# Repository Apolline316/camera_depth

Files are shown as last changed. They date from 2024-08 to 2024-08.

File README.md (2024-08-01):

# Depth Camera Usage Guide

In this section, you will learn how to create a depth map, including the software and hardware setup, as well as how to build a box to house all the components.

## Prerequisites

To complete this project, you will need the following components: (include links or sources for these)
- Raspberry Pi 5
- Time-of-Flight (ToF) sensor
- Binocular system composed of 2 IMX219 cameras
- Module V2.2 (camera multiplexer)
- 5V, 5A power supply
- Keyboard and mouse
- Screen with microHDMI cable (choose the type of cable based on your screen)

For building the box, you will need a 3D printer and PLA filament for printing.

You will also need a soldering iron, solder, and wires.

## Installation Guide

To set up a depth camera, first ensure you have all the components listed in the previous section.

The configuration for each component is provided in the respective component's folder.

Follow the installation in this order:

1. Setup the Raspberry Pi
2. Setup the ToF
3. Setup the binocular system

Make sure to match the configuration lines with those in the provided example.

Once these steps are completed, you can proceed to assemble the box and install your system.

## Box Assembly Guide

In this section, we will explain how to assemble the box (final image of the box). You will find the different parts to print in the 3D print folder. Note that supports are not included; you will need to add them during printing.

It is recommended to first follow the previous instructions and ensure that all systems are working before assembling the box. A component might be defective.

1. Connect the CSI cables to the Raspberry Pi.
2. Place the Raspberry Pi in its position. To insert it, angle it slightly due to the USB ports. You will need to apply a bit of force. The USB ports should protrude. You can then check the HDMI and USB-C ports.
3. Connect the CSI cables to the V2.2 module.
4. The V2.2 module comes with 2 standoffs. Insert the standoffs into the holes of the Raspberry Pi.
5. Place the module on the Raspberry Pi and secure it with screws onto the standoffs.
6. Insert the cameras into their designated slots and secure them with screws and bolts.
7. On the front panel: secure the ToF with screws and bolts.
8. Connect all cameras and the ToF to the Raspberry Pi.
9. Attach the front panel of the box: first secure the bottom holes, then the top ones.
10. Connect the microHDMI cable and the power supply.
11. Close the cover and connect the keyboard and mouse.
12. Power on the Raspberry Pi and check the camera connections by opening a terminal.

```bash
libcamera-still --list
```
Here is what you should see:
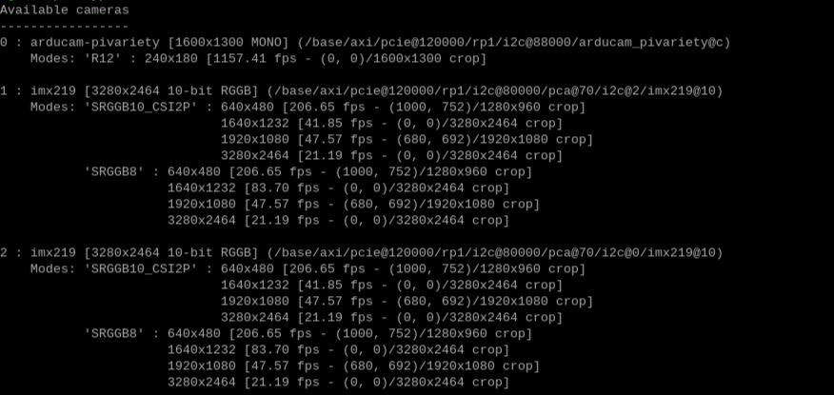
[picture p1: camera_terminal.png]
camera list


If you encounter any issues, repeat the steps. A cable may have become disconnected or may be connected incorrectly.

## Using the Depth Camera
After compiling the code, you can interact with it.

Press the following keyboard keys after clicking on the window you want to interact with:
- `q` to quit
- `s` to save images of the depth map
- `t` to analyze visible objects and determine their distance

To completely stop the code, press `CTRL+C`. However, you will need to restart the Raspberry Pi if you want to run the code again.

## Compilation

To compile the code, use the following line:

```bash
python main.py
```

## Code

### Class `DepthMapProcessor`
This class handles the processing of depth and disparity maps, including segmentation, calculation of average amplitudes, and contour drawing.

#### `__init__`
Initializes the `DepthMapProcessor` class with the provided parameters.

#### `apply_morphological_operations`
Applies morphological operations (dilation and erosion) to the specified image.

#### `calculate_mean_amplitude`
Calculates the mean amplitude for each specified contour.

#### `find_and_draw_contours`
Finds and draws contours in the processed image.

#### `process_contour`
Processes contours by applying morphological operations, finding and drawing contours, and calculating mean amplitudes for the detected contours.

#### `process_disparity_image`
Processes the disparity image by segmenting it according to the defined thresholds, then applying contour processing on each segment.

### Class `DualCameraCapture`
This class manages image capture with two cameras, including validating and displaying captured images.

#### `__init__`
Initializes parameters for image capture with two cameras.

#### `capture_and_save_image`
Captures and saves an image from the specified camera.

#### `display_images`
Displays captured images from specified files.

#### `validate_images`
Validates whether the captured images are acceptable.

#### `capture_images`
Captures a specified number of image pairs and saves them in the specified folder.

### Class `StereoVision`
This class handles stereo vision, including image capture, calculation of disparity and depth maps, and processing of depth maps.

#### `__init__`
Initializes parameters for stereo vision.

#### `stereo_taking`
Captures and rectifies stereo images.

#### `save_images`
Saves the images and the normalized disparity map.

#### `depth_map_calcul`
Calculates the disparity map from the rectified images.

#### `depth_calcul`
Calculates the depth for each pixel from the disparity map.

#### `process_stereo`
Processes the depth map using `DepthMapProcessor`.

#### `capture_and_compute`
Captures images, calculates the disparity and depth maps, and then queues the results.

#### `depth_map_display`
Displays the disparity map and depth from the queued results.

#### `process_and_display`
Creates processes for capturing and computing images, as well as displaying results.

### Functions

#### `folder_create`

Checks if a folder exists, otherwise it creates one.

#### `file_create`

Creates a file of the specified type in a given folder (optional).

#### `show_image`

Displays an image with a specified colormap.

#### `calibrate_cameras`

Calibrates cameras using a calibration process based on photos of a checkerboard.

#### `run_tof_camera`

Runs the ToF camera continuously and updates a queue with depth data.

#### `run_stereo_vision`

Performs stereo vision to obtain disparity and depth results.

#### `terminate_processes`

Terminates the specified processes.

#### `kill_zombie_processes`

Terminates zombie processes detected on the system.

#### `clean_temp_dirs`

Cleans up specified temporary directories.

#### `cleanup`

Performs system cleanup operations and frees up memory.

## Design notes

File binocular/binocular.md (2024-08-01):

# Camera Configuration

In this section, we will see how to configure the 2 IMX219 cameras (or other cameras) on an Arducam camera multiplexer (module V2.2).

<div style="display: flex; justify-content: space-between;">
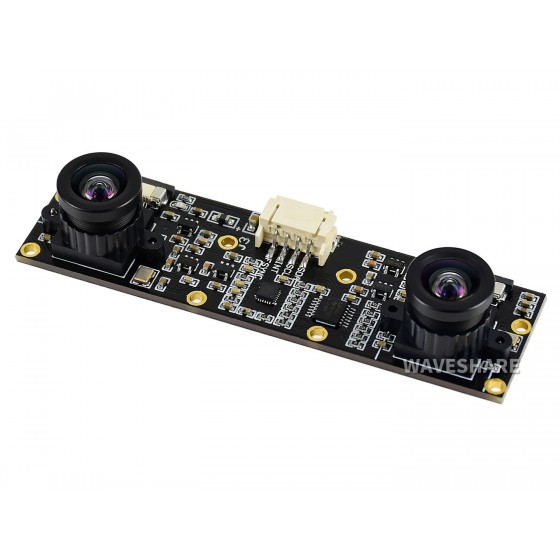
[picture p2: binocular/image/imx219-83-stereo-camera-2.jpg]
Stereo cameras
    
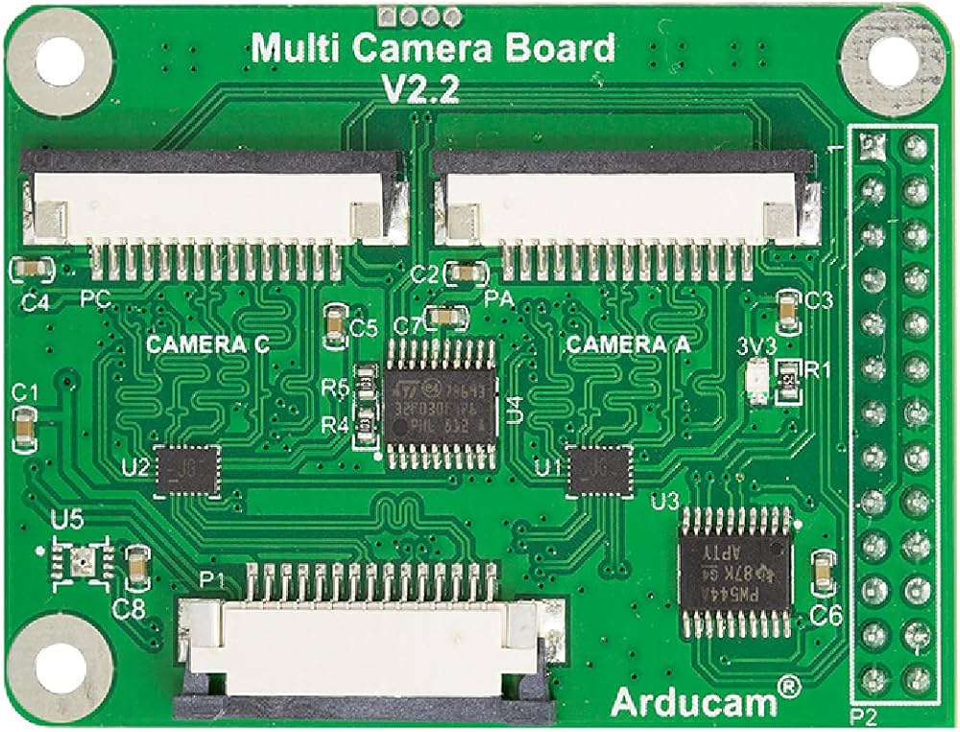
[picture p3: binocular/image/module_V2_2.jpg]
module V2.2
    
</div>

First, make sure you have the appropriate camera cables for use with the V2.2 module.

To get the cameras to work on this module, they must be of the same model.

In a terminal, open the configuration file:
```bash
sudo nano /boot/firmware/config.txt
```

In the configuration file, you will need to add the following lines:
```ini
dtoverlay=arducam-pivariety,cam1
dtoverlay=camera-mux-4port,cam0-imx219,cam2-imx219
```
You will then need to associate each port with its number. Here is the letter-to-number correspondence:
- cam0: A
- cam1: B
- cam2: C
- cam3: D

# Stereo Camera Calibration

In this section, we will see how to calibrate the cameras so they can be used. This calibration will allow us to know the intrinsic and extrinsic parameters of our cameras.

The principle of stereo vision is to have a matrix on the right and left for each camera. Each element of our cameras is stored in dictionaries.

If you want to understand the principle of a binocular system, please refer to the document mathematics_model.pdf. It outlines the mathematical modeling.

To save your calibration, the data is automatically recorded in the 'data' folder. Reuse is also automatic. You will not need to modify the code.

## Calibration Process
To calibrate the cameras, you need a chessboard. You can print the provided file. However, you must ensure it is rigid to prevent calculation errors due to camera distortion.

When you indicate you want to calibrate the cameras by entering 'y', you will have the option to specify the number of rows and columns on the chessboard, as well as the number of images you want to take.

Take different positions with the chessboard. However, make sure it is entirely within the images and close enough to the cameras for the best calibration quality. You can validate or invalidate the taken images if they do not meet your expectations.

## Measurement Process

Images are taken automatically, with delays. However, you can set delays by modifying the class at the time of its declaration in stere_vision.py.

A window will then open to view the map. You can modify the depth camera filter values if necessary, if the result is not satisfactory.

# The Code

## Code Description
In this section, we will see the different classes and functions that allow calculating the depth map, calibrating, and capturing images with the cameras.

## StereoCalibration

### Description
Manages the parameters and processes of stereoscopic calibration for two cameras.

### Methods

#### `__str__(self)`
Returns a string representation of the class attributes.

#### `__init__(self)`
Initializes the calibration parameters for stereo cameras.

#### `save_data(self)`
Saves the calibration parameters in `.npy` and `.csv` files.

#### `rectify(self, frames: list) -> list`
Rectifies the stereoscopic images using the undistortion and rectification maps.

#### `load_data(self, directory: str)`
Loads the calibration parameters from `.npy` files in a specified directory.

## Calibrator

### Description
Manages the calibration process for a pair of stereo cameras.

### Methods

#### `__init__(self, row: int, column: int, square_size: float, image_size: tuple)`
Initializes the parameters for camera calibration.

#### `corner_detect(self, image_pair: tuple)`
Detects the corners of the calibration board in a pair of images.

#### `calibrate_camera(self) -> StereoCalibration`
Calibrates the two cameras and determines their related matrices.

#### `calibration_process(self, nbr_photo: int, image_folder: str) -> StereoCalibration`
Performs the calibration process by reading calibration images and calling the calibration method.

## DualCameraCapture

### Methods

#### `__init__(self)`
Initializes the parameters for capturing images with two cameras.

#### `capture_and_save_image(self)`
Captures and saves an image from the specified camera.

#### `display_images(self)`
Displays the captured images from the specified files.

#### `validate_images(self)`
Validates if the captured images are acceptable.

#### `capture_images(self)`
Captures a specified number of image pairs and saves them in the specified folder.

## StereoVision

### Methods

#### `__init__(self)`
Initializes the parameters for stereo vision.

#### `stereo_taking(self)`
Captures and rectifies stereo images.

#### `save_images(self)`
Saves the images and the normalized disparity map.

#### `depth_map_calcul(self)`
Calculates the disparity map from the rectified images.

#### `depth_calcul(self)`
Calculates the depth for each pixel from the disparity map.

#### `process_stereo(self)`
Processes the depth map using `DepthMapProcessor`.

#### `capture_and_compute(self)`
Captures images, calculates the disparity map and depth, then places the results in a queue.

#### `depth_map_display(self)`
Displays the disparity map and depth from the results in the queue.

#### `process_and_display(self)`
Creates processes for capturing and computing images, as well as for displaying the results.

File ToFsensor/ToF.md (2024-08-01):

# Time-of-Flight (ToF) Sensor Configuration

This document provides instructions for configuring a time-of-flight (ToF) sensor on your Raspberry Pi 5. Initially, we will see how to initialize the sensor on the Raspberry Pi. Once these steps are completed, you will not need to redo them. You can then simply compile the code.

## Required Hardware

Before you start, make sure you have the following items:

- Compatible Raspberry Pi
- Time-of-Flight (ToF) sensor
- GPIO cable (if necessary)
- Male-to-Male Dupont cable

## Configuration Steps

### Connecting to the Raspberry Pi 5

Connect the CSI cable to the cam 0 port (the one closest to the Ethernet connector), and connect the 5V and GND to the pins, as shown in the following schematic:

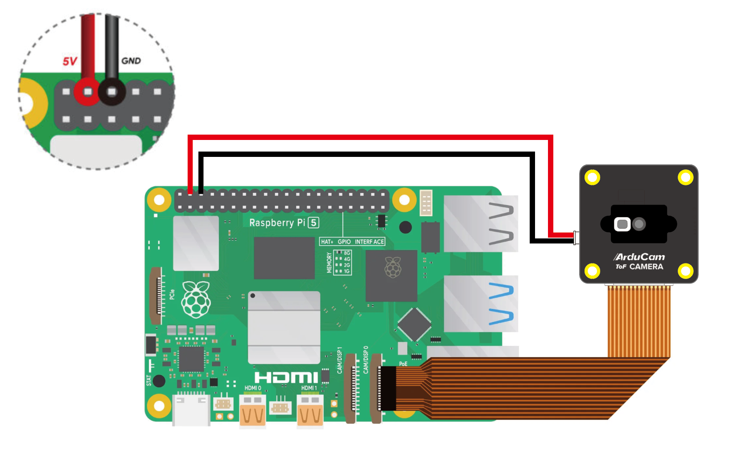
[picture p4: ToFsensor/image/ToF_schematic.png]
Tof sensor connectic


### Step 1. Connect the Arducam ToF Camera to the Raspberry Pi

Note that the Raspberry Pi should remain turned off during the connection, and the power cable should be removed.

### Step 2. Keep Your Raspberry Pi Powered Off

Please keep your Raspberry Pi powered off and activate the recovery on the Arducam ToF camera board using the Dupont line (a male-to-male cable may suffice if you do not have a Dupont line):

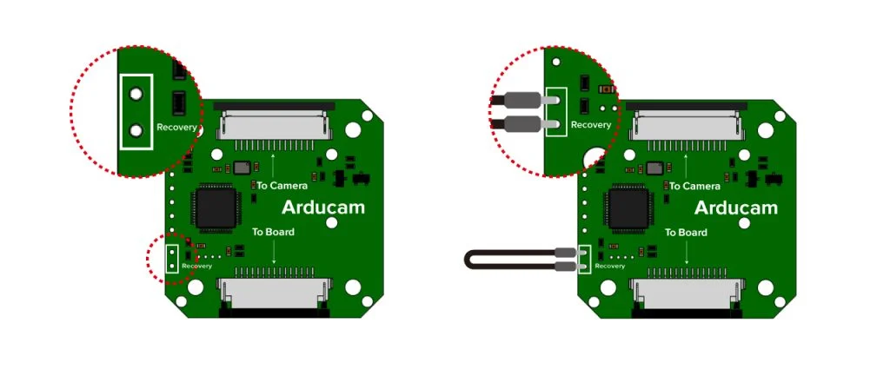
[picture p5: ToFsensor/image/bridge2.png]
Camera Schematic (Step 2)


### Step 3. Turn On Your Raspberry Pi

Please deactivate the recovery after turning on the RPi:

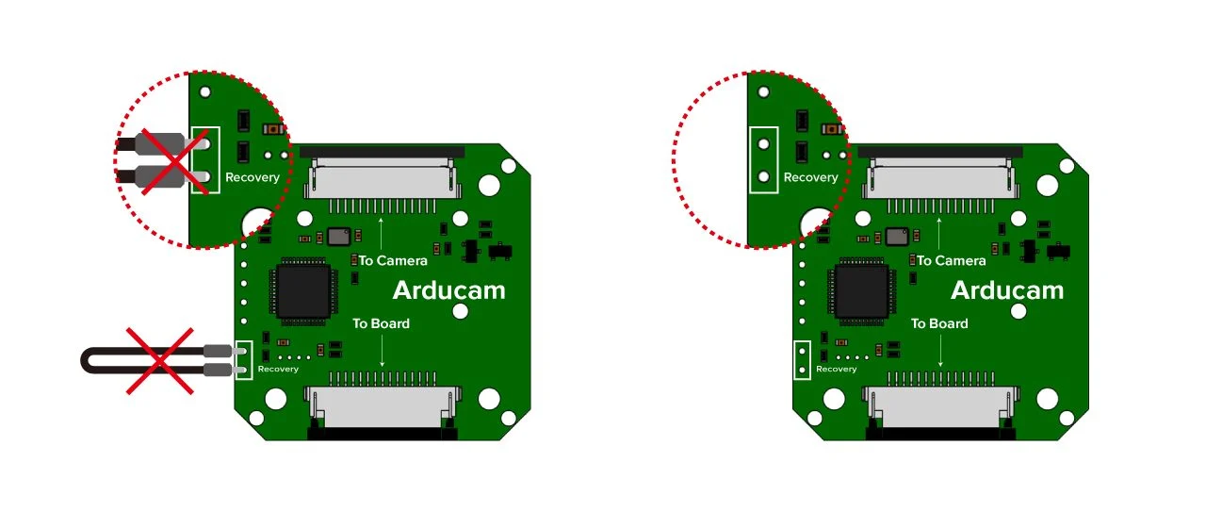
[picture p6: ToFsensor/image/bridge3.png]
Camera Schematic (Step 3)


Simply remove the Dupont line.

## Download the Firmware Update Tool

```bash
B0410_Tof_firmware.tar.gz
```

## Install Dependencies

```bash
sudo apt update -y && sudo apt install -y libtinfo5
```

## Unzip the Update Tool

### Tip

You can check whether your system is 32-bit or 64-bit by using the command `dpkg --print-architecture`. Then, you can execute the following commands based on the version of your operating system:

```bash
tar xzvf B0410_Tof_Firmware.tar.gz
# for a 64 bits system
cd B0410_Tof_Firmware/aarch64/

# for a 32 bits system
cd B0410_Tof_Firmware/armv7l/
```

## Update the Firmware

### Check the I2C Bus

You can then check the I2C connection:

```bash
dmesg | grep arducam
```
You should see the code x-000c.

By default, the code is 4-000c. However, this code may change.

Tof sensor config 1

### Update the I2C Bus

Next, you need to update the firmware. To do this, enter the following line in your terminal:
Make sure to replace `x` with the I2C bus port number.

```bash
sudo ./firmware_update -i x -m b0410_tof_firmware
```

Check that the address is `0xFFFFFFFE` on the first lines.

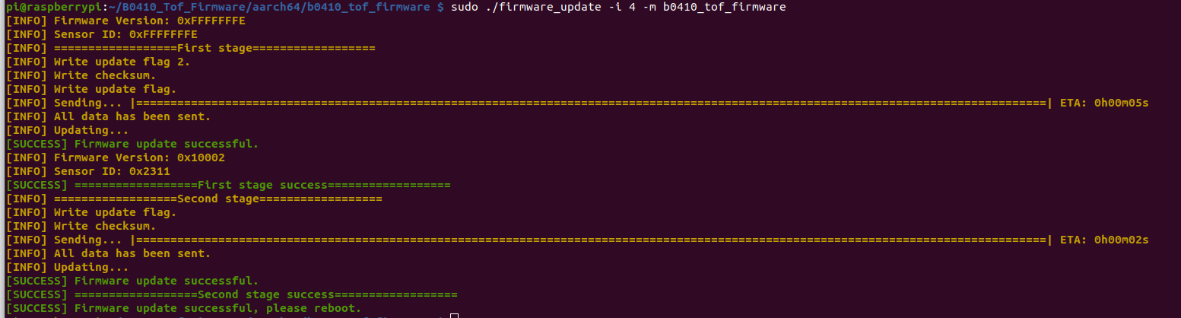
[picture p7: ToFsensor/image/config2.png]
Tof sensor config 2


If not, repeat the steps to connect the sensor. You will need to redo the last 2 steps.

### Reboot

Next, restart your system.

``` bash
sudo reboot
```

## Using the Camera

To use the camera, follow these steps:

### Step 1. Download the Git Repository

``` bash
git clone https://github.com/ArduCAM/Arducam_tof_camera.git
```
### Step 2. Enter in the folder

``` bash
cd Arducam_tof_camera
```
### Step 3. Install the dependencies

``` bash
./Install_dependencies.sh
```
Enter 'y' for reboot the Raspberry Pi.

You can verify thzt the next line is in your config.txt file.

``` bash
dtoverlay = arducam-pivariety,cam0
```

### Step 4. Compile

Compile the code to check its functionality and install any missing components.

``` bash
./compile.sh
```
The live camera feed should then open. Use `Ctrl + C` to stop the code.

### Step 5. Python Configuration

Enter this line in the terminal:
``` bash
./Install_dependencies_python.sh
```

It may be necessary from time to time to redo steps 3 and 4. Indeed, some libraries may need to be updated, or the connection with the ToF sensor might be lost. You do not need to redo step 5.

# The Code

The goal of this code is to operate the ToF sensor through a process. To make it work, please refer to `main.py`.

In the following sections of this guide, we will review the source file `tof_sensor.py`.

## Code Description

### Description

The `TofCamera` class manages image capture from a Time-of-Flight (ToF) camera, processes depth and amplitude data, and displays the results.

### Methods

#### `__init__(self, max_distance: float)`

Initializes the ToF camera with the maximum measurable distance.

#### `process_frame(self) -> np.ndarray`

Processes the captured frame and returns the resulting image.

#### `capture_image(self)`

Saves the resulting image under the name `tof{n}.png`.

#### `process_tof(self)`

Processes the depth map to extract contours.

#### `continuous_display(self)`

Continuously captures and displays images from the ToF camera.

#### `cleanup(self)`

Stops and closes the camera, and destroys all OpenCV windows.

#### `get_depth_buf(self) -> np.ndarray`

Returns the current depth buffer.

#### `get_depth_normalized(self) -> np.ndarray`

Returns the normalized depth map.

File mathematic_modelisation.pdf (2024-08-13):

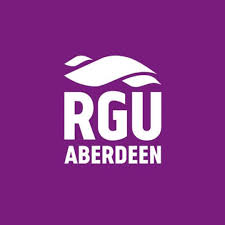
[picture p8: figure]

### MATHEMATIC MODELISATION OF A DEPTH

### CAMERA

### BOYER Apolline

### August 13, 2024

## Contents

2.3.2 Calculating the Transformation Matrix Between the Two

1

Mathematic modelisation of a depth camera

### 1 Introduction

The objective is to do a mathematic modelisation of a depth camera. This depth camera will use a binolucar camera which permits to make a stereo vision of an image. A Time-of-Flight sensor is also used.
First, we will see the modelisation of a binocular system. Then, we will see the modelisation of a Time-of-Flight sensor.

### 2 The Binocular System

Binocular vision, inspired by the human ability to perceive depth and the three-dimensional structure of the world, uses two cameras to capture images of the same scene from slightly different angles. By exploiting disparity, which is the difference in the position of objects in the two images, it is possible to calculate the distance of objects relative to the cameras and thereby reconstruct a three-dimensional scene.

### 2.1 Camera Modeling

A camera is modeled using the pinhole model. It allows the conversion from a 3D image to a 2D image.
This is done through three transformations. The first transformation consists of converting from a 3D reference frame to the camera reference frame. The second transformation allows for a projection onto the image. Finally, the third transformation converts dimensions from mm to pixels.The two last are rerouped in one tranformation.

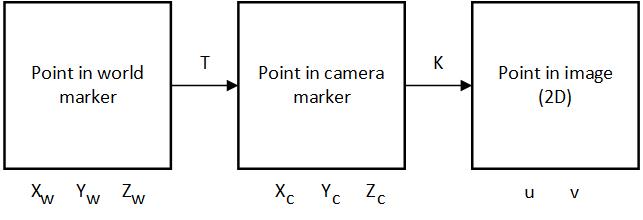
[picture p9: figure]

Figure 1: Schematic of different transformations

First, we take a point M in what is called the world coordinate system. M has coordinates (XW ,YW ,ZW ). The point C is the projection of M (XC ,YC ,ZC ) in the camera reference frame. The point m (u, v) is the projection of C in the image reference frame.

2

Mathematic modelisation of a depth camera

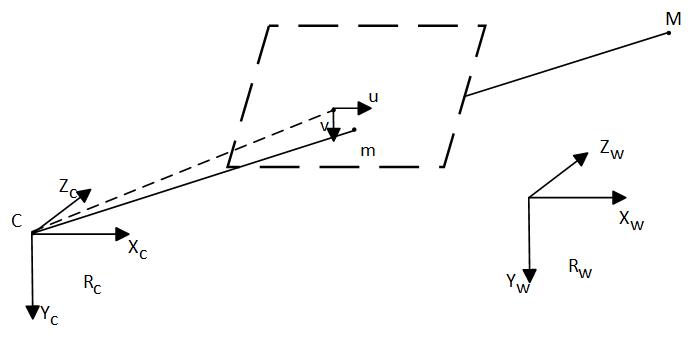
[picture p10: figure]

Figure 2: Schematic for transformation

First of all, we can see the transformation from M to C as a combination of rotations and translations, all in homogeneous coordinates.
The rotation matrices around the three principal axes are defined as follows:

Rotation around the X-axis (angle α) :

Rx (α) =

1 | 0 | 0
0 cosα −sinα
0 | sinα | cosα

Rotation around the Y-axis (angle β) :

Ry (β) =

cosβ | 0 | sinβ
0 | 1 | 0
−sinβ 0 cosβ

Rotation around the Z-axis (angle γ) :

Rz (γ) =

cosγ −sinγ 0
sinγ | cosγ | 0
0 | 0 | 1

The translation vector is:

T (Tx ,Ty ,Tz ) =

| Tx
| Ty
| Tz

In homogeneous coordinates, rotations and translation can be combined into a single transformation matrix T .

3

Mathematic modelisation of a depth camera

The homogeneous transformation matrix T is obtained by combining the rotation matrices and the translation vector:

T =

Ã
R | t
0 | 1!
(1)

Where R is the combined rotation matrix and t is the translation vector.
The combined rotation matrix can be obtained by multiplying the individual rotation matrices (according to the desired order of rotations):

R = Rz (γ)Ry (β)Rx (α)

Thus, the complete homogeneous transformation matrix T is:

T =

cosβcosγ | −cosβsinγ | sinβ | Tx
sinαsinβcosγ+cosαsinγ | −sinαsinβsinγ+cosαcosγ −sinαcosβ Ty
−cosαsinβcosγ+sinαsinγ | cosαsinβsinγ+sinαcosγ | cosαcosβ | Tz
0 | 0 | 0 | 1

(2)

The matrix T corresponds to the extrinsic parameters of the camera.

The intrinsic parameters of a camera are used to transform the 3D coordinates in the camera reference frame into 2D coordinates in the image reference frame. These parameters include the focal lengths fx and f y , as well as the principal point coordinates cx and cy .

The transformation of camera coordinates (XC ,YC ,ZC ) to image coordinates (u, v) is carried out in three steps:
1. Perspective projection: This transformation projects the 3D coordinates onto an image plane.
2. Scaling: This transformation converts the units of the image coordinates from mm to pixels.
3. Translation: This transformation adjusts the image coordinates to account for the principal point of the image.

The intrinsic projection matrix K is defined as follows:

4

Mathematic modelisation of a depth camera

K =

fx | 0 | cx | 0
0 | f y | cy | 0
0 | 0 | 1 | 0

(3)

Thus, for a point C in the camera reference frame with homogeneous coordinates (XC ,YC ,ZC , 1), the homogeneous coordinates of the projected point m in the image reference frame are obtained by:

u
v
1

- = K

XC
YC
ZC
1

=

fx | 0 | cx | 0
0 | f y | cy | 0
0 | 0 | 1 | 0

XC
YC
ZC
1

(4)

By combining the extrinsic and intrinsic transformations, the complete projection matrix M of the camera is:

M = K ·T =

fx | 0 | cx | 0
0 | f y | cy | 0
0 | 0 | 1 | 0

R11 | R12 | R13 | Tx
R21 | R22 | R23 | Ty
R31 | R32 | R33 | Tz
0 | 0 | 0 | 1

(5)

### 2.2 Camera Calibration

The objective of calibration is to find the values of the elements mi j of the matrix M that minimize the projection error between the 3D coordinates of the real world and the observed 2D coordinates of the image. This can be achieved using optimization algorithms such as the least squares method.

First, we need to determine the system of equations between the different parameters. We have:

su
sv
s

- = M

XW
YW
ZW
1

where (XW ,YW ,ZW ) are the 3D coordinates of the point in the world coordinate system, (u, v) are the 2D coordinates of the image in pixels, s is a scale factor, and M is the projection matrix.

Divide the equations by s to obtain the normalized coordinates:

5

Mathematic modelisation of a depth camera

u =

m11XW +m12YW +m13ZW +m14
s

v =

m21XW +m22YW +m23ZW +m24
s

s = m31XW +m32YW +m33ZW +m34

(6)

By substituting s into the previous equations, the normalized coordinates (u, v) be-come:

u =

m11XW +m12YW +m13ZW +m14

m31XW +m32YW +m33ZW +m34

v =

m21XW +m22YW +m23ZW +m24

m31XW +m32YW +m33ZW +m34

(7)

These equations represent the projection of a world point into an image point using the matrix M with its elements mi j, considering the factor s.
We then have the following system of equations:

0 = m11XW +m12YW +m13ZW +m14 −u ·m31XW −u ·m32YW −u ·m33ZW −u ·m34

0 = m21XW +m22YW +m23ZW +m24 − v ·m31XW − v ·m32YW − v ·m33ZW − v ·m34

(8)

To calibrate the camera, we need to solve this system of equations for multiple points (XW ,YW ,ZW ) and their correspondences (u, v). Using N points, we obtain a system of 2N linear equations, which can be expressed in matrix form to be solved using the least squares method:

6

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

Mathematic modelisation of a depth camera

U = K2N .Q | (9)

Additionally, by observing the relationships in the rotation matrix, we can deduce the following relationship:

m²

31 +m²

32 +m²
33 = 1 | (10)

From this, we can deduce the following relationship:

m34 =

s
1
q

2
31 + q

2
32 + q

2
33

(11)

Equation (9) is then solved using the least squares method. We obtain the result:

Q = (K

t
2N

.K2N )

−1K

t
2N
.U | (12)

Once the matrix Q is determined, and using equation (11), we can then determine the elements mi j.

Next, we want to calculate the intrinsic and extrinsic parameters.

From the relation (4), we obtain the following system of equations:

m11 = fxR11 +cxR31

m12 = fxR12 +cxR32

m13 = fxR13 +cxR33

m14 = fxTx +cxTz

m21 = f yR21 +cyR31

m22 = f yR22 +cyR32

m23 = f yR23 +cyR33

m24 = f yTy +cyTz

m31 = R31

m32 = R32

m33 = R33

m34 = Tz

(13)

Let mi = (mi1,mi2,mi3).

8

Mathematic modelisation of a depth camera

The relationships to find all the elements are:

r3 = m3

cx = m1 ·m3

cy = m2 ·m3

fx = −∥m1 ∧m3∥

f y = ∥m2 ∧m3∥

r1 =

1
fx

(m1 −cxm3)

r2 =

1
f y

¡
m2 −cym3

¢

tx =

1
fx

(m14 −cxm34)

ty =

1
f y

¡

m24 −cym34¢

tz = m34

(14)

### 2.3 Stereo Vision: Using Two Cameras

### 2.3.1 Principle of Stereo Vision

Stereo vision is a technique that uses two cameras placed at slightly different positions to capture a scene. By exploiting the differences in perspective between the two obtained images, it is possible to reconstruct the three-dimensional structure of the scene. The basic principle of stereo vision is based on triangulation. By comparing the positions of the same point in the two images, we can determine its depth using the geometry of the triangles formed by the optical rays and the optical axes of the cameras.

Specifically, for each corresponding point in the two images, a line of sight is drawn from the optical center of each camera to the point. The 3D position of the point is then determined by the intersection of these two lines of sight. This process is repeated for several points in the image to reconstruct the scene in three dimensions.

### 2.3.2 Calculating the Transformation Matrix Between the Two Images

When using two cameras to capture a scene in stereo view, it is often necessary to calculate the transformation matrix between the two images. This matrix, usually called the transformation matrix or displacement matrix, aligns the corresponding points in the two images to facilitate comparison and three-dimensional reconstruction of the scene.

9

Mathematic modelisation of a depth camera

The transformation matrix is generally calculated using image registration or feature matching techniques. These techniques can include algorithms such as interest point matching, texture matching, or descriptor-based methods.
Once the corresponding points have been identified in the two images, the transformation matrix can be calculated from these correspondences. This matrix is essentially a geometric transformation that expresses the displacement and orientation needed to align the two images.

Let Ai be the projection matrix that transforms coordinates from the world frame to the camera frame.

Ai =

R

i

11 | R i
| 12 | R i
| | 13 | t i
| | | x
R

i

21 | R i
| 22 | R i
| | 23 | t i
| | | y
R

i

31 | R i
| 32 | R i
| | 33 | t i
| | | z
0 | 0 | 0 | 1

The projection matrices of the left and right cameras are denoted as AL and AR, respectively. These matrices can be defined as follows:

PC i = Ai

·PW | (15)

where PC i represents the projected coordinates in the camera frame (left or right) and PW represents the coordinates of the point in the world frame.

We can then deduce the matrix that transforms coordinates from the right camera frame to the left camera frame:

PCR = AsPC L

where As = AR · A

−1
L
| (16)

We have

As =

R11 | R12 | R13 | tx
R21 | R22 | R23 | ty
R31 | R32 | R33 | tz
0 | 0 | 0 | 1

We define the two points as follows:

PCR =

XR
YR
ZR

10

Mathematic modelisation of a depth camera

PC L =

XL
YL
ZL

We then have the following system of equations:

XR = R11XL +R12YL +R13ZL + tx

YR = R21XL +R22YL +R23ZL + ty

ZR = R31XL +R32YL +R33ZL + tz

(17)

The goal is to eliminate ZL. By setting xR =

XR
ZR

and yR =

YR
ZR

, we develop the following:

xR =

XR
ZR

=

R11XL +R12YL +R13ZL + tx

R31XL +R32YL +R33ZL + tz

yR =

YR
ZR

=

R21XL +R22YL +R23ZL + ty

R31XL +R32YL +R33ZL + tz

From these equations, we can express ZL as follows:

ZL =

tx − xR tz

xRR31xL + xRR32 yL + xRR33 −R11xL −R12 yL −R13

ZL =

ty − yR tz

yRR31xL + yRR32 yL + yRR33 −R21xL −R22 yL −R23

By setting these expressions equal, we obtain the following right equation:

a.xR +b.yR +c = 0

where: a = (R31tY −R21tZ )xL +(R32tY −R22tZ ) yL +R33tY −R23tZ

b = (R11tZ −R31tX )xL +(R12tZ −R32tX ) yL +R13tZ −R33tX

c = (R21tX −R11tY )xL +(R22tX −R12tY ) yL +R23tX −R13tY

(18)

This line allows for estimating the correspondence between points in the right camera frame and the left camera frame. It is known as an epipolar line.

Epipolar geometry provides a crucial framework for understanding the spatial relationships between images captured by two cameras. A key aspect of this geometry is the concept of epipolar lines, which emerge from the essential matrix E that describes the fundamental properties of the scene and the cameras. Similarly, the fundamental matrix F offers a mathematical representation of the epipolar geometry, highlighting the projective relationships between corresponding points in stereo images.
Indeed, epipolar lines are of critical importance in the process of finding correspondences between points in stereo images, a necessary step for applications such as stereo triangulation and three-dimensional reconstruction.

11

Mathematic modelisation of a depth camera

In the following section, we will closely examine the calculations associated with the essential matrix E and the fundamental matrix F, as well as their impact on determining epipolar lines. We will also explore the practical implications of these concepts for stereo vision, highlighting the methods and algorithms used to effectively exploit epipolar lines in practical applications.

### 2.3.3 Epipolar Geometry

To express the essential matrix E in terms of the rotation matrix related to As, we need to decompose As into its rotation and translation components.
The matrix As is defined as follows:

As =

Ã
R | t
0 | 1!

where R is the rotation matrix and t is the translation vector.
We can then refer back to the epipolar line equation (18). We can express the elements a, b, and c as:

a
b
c

- = E ·

xL
yL
1

(19)

We can write E from the rotation matrix R and the translation vector t:

E = [t]×R

The antisymmetric matrix [t]× is then defined as:

[t]× =

0 | −tz | ty
tz | 0 | −tx
−ty | tx | 0

By combining these elements, we obtain:

E =

0 | −tz | ty
tz | 0 | −tx
−ty | tx | 0

R | (20)

We can rewrite the epipolar line as the equation:

P

t
CREPC L = 0 | (21)

12

Mathematic modelisation of a depth camera

Next, we want to calculate the fundamental matrix F. For this, we need to revisit the projection from the camera frame to the image frame.

pR = KRPCR

pL = KLPC L

By substituting the homogeneous coordinates, we get:

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
pL) = 0

Which expands to:
p

T
RK

−T
R

EK ⁻¹
L

pL = 0

We define the fundamental matrix F in terms of the essential matrix E and the intrinsic matrices:
F = K

−T
R

EK ⁻¹
L

(22)

The epipolar equation then becomes:

p

T
R
FpL = 0 | (23)

Thus, we have a relationship between the image coordinates of the right camera and the left camera.

### 2.4 Depth Calculation

Depth calculation is a crucial step in stereo vision, allowing the reconstruction of the three-dimensional structure of a scene from two-dimensional images. By exploiting the differences in the positions of corresponding points in the two images (disparity), it is possible to determine the distance of these points from the cameras.

### 2.4.1 Principle of Disparity

Disparity refers to the difference in position of the same point in the two images captured by stereo cameras. Specifically, if a point in the scene is projected onto the left and right images at coordinates (xL, yL) and (xR, yR) respectively, the disparity d is defined as:

d = xL − xR | (24)

Disparity is directly related to the depth of the point in the scene. Points closer to the cameras will have a larger disparity, while points further away will have a smaller disparity.

13

Mathematic modelisation of a depth camera

### 2.4.2 Relationship between Disparity and Depth

The depth Z of a point in the scene can be calculated using the disparity and the camera parameters. For horizontally aligned stereo cameras, the relationship between depth and disparity is given by:

Z =

f ·B
d

(25)

where:

- Z is the depth of the point.
- f is the focal length of the cameras.
- B is the stereo baseline, i.e., the distance between the two cameras.
- d is the disparity of the point.

The depth calculation described above is valid in the case where the optical axes of the cameras are parallel and one of the image axes is aligned. This configuration is common in standard stereo vision systems, where the cameras are horizontally aligned and their image planes are parallel to the stereo baseline.

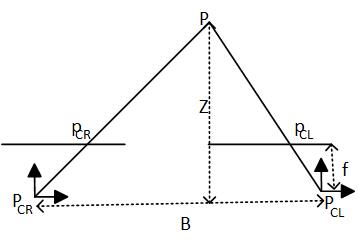
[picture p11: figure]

Figure 3: Schematic of stereo vision

It is important to note that deviations from these ideal conditions can introduce errors in depth calculation. For instance, optical distortions, image deformations, and camera misalignments can affect the accuracy of disparity measurements and introduce errors in depth estimates.

### 3 Time⁻of⁻Flight (ToF) Sensors

### 3.1 Principle of ToF Sensors

Time-of-Flight (ToF) sensors operate on the principle of measuring the time it takes for a light signal to travel a given distance and return to the sensor. To do this, the sensor

14

Mathematic modelisation of a depth camera

emits a light signal, usually a laser beam, towards the object to be measured. This signal is then reflected by the object and returned to the sensor. By measuring the time elapsed between the emission and reception of the signal, the sensor can determine the distance between itself and the object.

### 3.1.1 ToF Related Calculations

When the optical axes of the cameras are parallel and one of the image axes is aligned, it is possible to calculate the distance between the sensor and the object using the following equation:

Distance =

c ×∆t
2

(26)

In this equation:

- Distance represents the distance between the sensor and the target object.
- c is the speed of light in the propagation medium (typically air).
- ∆t is the time difference between the emission and reception of the light signal.

This equation allows for the calculation of the distance between the sensor and the object using the measured time of flight and the speed of light.

15

Mathematic modelisation of a depth camera

### 4 Conclusion

Consequently, the different equations necessary for a depth camera with a binocular system and a ToF sensor, are :

Projection matrix M :

M = K ·T =

fx | 0 | cx | 0
0 | f y | cy | 0
0 | 0 | 1 | 0

R11 | R12 | R13 | Tx
R21 | R22 | R23 | Ty
R31 | R32 | R33 | Tz
0 | 0 | 0 | 1

Least Square result :
Q = (K

t
2N

.K2N )

−1K

t
2N

.U

The relationships to find all the elements

r3 = m3

cx = m1 ·m3

cy = m2 ·m3

fx = −∥m1 ∧m3∥

f y = ∥m2 ∧m3∥

r1 =

1
fx

(m1 −cxm3)

r2 =

1
f y

¡
m2 −cym3

¢

tx =

1
fx

(m14 −cxm34)

ty =

1
f y

¡

m24 −cym34¢

tz = m34

Essential matrix

E =

0 | −tz | ty
tz | 0 | −tx
−ty | tx | 0

R

Fondamentale F
F = K

−T
R

EK ⁻¹
L

16

Mathematic modelisation of a depth camera

Epipolar line equation
P

t
CREPC L = 0

p

T
R

FpL = 0

Depth equation

Z =

f ·B
d

ToF sensor equation

Distance =

c ×∆t
2

17
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

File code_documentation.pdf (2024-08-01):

# Python Code Documentation

### Apolline Boyer

### August 1, 2024

## Contents

1 Classes and Functions | 3

2 Functions | 18
3 Camera and Process Management | 19
4 Main Script Execution | 21

## 1 Classes and Functions

### 1.1 Class StereoCalibration

- Description: This class manages the parameters and processes of stereo calibration for two cameras.
- Attributes:

– cam mats: Dictionary of camera matrices (intrinsic parameters) for the left and right cameras.

– dist coefs: Dictionary of distortion coefficients for the left and right cameras.

– rot mat: Rotation matrix.

– trans vec: Translation vector.

– e mat: Essential matrix.

– f mat: Fundamental matrix.

– rect trans: Dictionary of rectification transformations for the left and right cameras.

– proj mats: Dictionary of projection matrices for the left and right cameras.

– disp to depth mat: Disparity-to-depth conversion matrix.

– valid boxes: Dictionary of valid pixel bounding boxes for the left and right cameras.

– undistortion map: Dictionary of undistortion maps for the left and right cameras.

– rectification map: Dictionary of rectification maps for the left and right cameras.

1.1.1 | Method | str
- Description: Returns a string representation of the class attributes.
- Arguments: None.
- Returns: str - String representation of the object’s attributes.
- Usage Example:
1 | print ( calibration )
1.1.2 | Method | init
- Description: Initializes the calibration parameters for stereo cameras.
- Arguments: None.
- Returns: None.

- Usage Example:

1 calibration = StereoCalibration ()

### 1.1.3 Method save data

- Description: Saves the calibration parameters to .npy and .csv files.
- Arguments: None.
- Returns: None.
- Usage Example:

1 calibration . save_data ()

### 1.1.4 Method rectify

- Description: Rectifies stereo images using undistortion and rectification maps.
- Arguments:

– frames: list - List of left and right camera images.

- Returns: list - List of rectified images.
- Usage Example:

1 rectified_frames = calibration . rectify ( frames )

### 1.1.5 Method load data

- Description: Loads calibration parameters from .npy files in a specified directory.
- Arguments:

– directory: str - Directory containing the parameter files.

- Returns: None.
- Usage Example:

1 calibration . load_data (’ calibration_data ’)

### 1.2 Class Calibrator

- Description: Manages the calibration process for a pair of stereo cameras.
- Attributes:

– image count: Number of calibration images used.

– row: Number of internal corners in the rows of the calibration pattern.

– column: Number of internal corners in the columns of the calibration pattern.

– square size: Size of the calibration pattern squares in cm.

– image size: Size of calibration images in pixels.

– corner coordinates: 3D coordinates of the calibration pattern corners.

– object points: List of coordinates of real corners found in each image.

– image points: Dictionary of coordinates of corners found in the images for the left and right cameras.

1.2.1 | Method | init
- Description: Initializes the parameters for camera calibration.
- Arguments:

– row: int - Number of internal corners in the rows of the pattern.

– column: int - Number of internal corners in the columns of the pattern.

– square size: float - Size of the pattern squares in cm.

– image size: tuple - Size of calibration images in pixels.

- Returns: None.
- Usage Example:

1 calibrator = Calibrator ( row =6 , column =9 , square_size =2.5 , image_size =(1920 , 1080) )

### 1.2.2 Method corner detect

- Description: Detects the corners of the calibration pattern in a pair of images.
- Arguments:

– image pair: tuple - Tuple containing the left and right images.

- Returns: None.
- Usage Example:

1 calibrator . corner_detect (( left_image , right_image ) )

### 1.2.3 Method calibrate camera

- Description: Calibrates both cameras and determines their related matrices.
- Arguments: None.
- Returns: StereoCalibration - Instance of the StereoCalibration class with calibrated parameters.
- Usage Example:

1 calibration = calibrator . calibrate_camera ()

### 1.2.4 Method calibration process

- Description: Performs the calibration process by reading the calibration images and calling the calibration method.
- Arguments:

– nbr photo: int - Number of calibration images to process.

– image folder: str - Directory containing the calibration images.

- Returns: StereoCalibration - Instance of the StereoCalibration class with the calibrated parameters.
- Usage example:

1 calibration = calibrator . calibration_process ( nbr_photo =20 , image_folder =’ calibration_images ’)

### 1.3 Class DualCameraCapture

- Description: Captures stereo images using two cameras and provides tools to display and validate these images.
- Attributes:

– left cam id: ID of the left camera.

– right cam id: ID of the right camera.

– preview size: Size of the preview of the captured images.

– preview type: Type of preview.

– capture delay: Delay before capturing the image.

– interval: Interval between image captures.

1.3.1 | Method | init
- Description: Initializes the parameters for capturing images with two cameras.
- Arguments:

– left cam id: int - ID of the left camera.

– right cam id: int - ID of the right camera.

– preview size: tuple - Size of the preview.

– preview type: Preview - Type of preview.

– capture delay: float - Delay before capturing the image.

– interval: float - Interval between image captures.

- Returns: None.
- Usage example:

1 capture = DualCameraCapture ( left_cam_id =0 , right_cam_id =1 , preview_size =(800 , 600) , capture_delay =2 , interval =5)

### 1.3.2 Method capture and save image

- Description: Captures and saves an image from the specified camera.
- Arguments:

– picam id: int - ID of the camera to use.

– filename: str - Filename to save the image.

- Returns: None.
- Usage example:

1 capture . capture_and_save_image ( picam_id =0 , filename =’left_image .png ’)

### 1.3.3 Method display images

- Description: Displays the captured images from the specified files.
- Arguments:

– left filename: str - Filename of the left image.

– right filename: str - Filename of the right image.

- Returns: None.
- Usage example:

1 capture . display_images ( left_filename =’left_image .png ’, right_filename =’right_image .png ’)

### 1.3.4 Method validate images

- Description: Validates if the captured images are acceptable.
- Arguments: None.
- Returns: bool - Returns True if the images are acceptable, otherwise False.
- Usage example:

1 is_valid = capture . validate_images ()

### 1.3.5 Method capture images

- Description: Captures a specified number of image pairs and saves them in the specified folder.
- Arguments:

– nbr photos: int - Number of image pairs to capture.

– image folder: str - Folder to save the images.

- Returns: None.
- Usage example:

1 capture . capture_images ( nbr_photos =10 , image_folder =’ captured_images ’)

### 1.4 Class StereoVision

- Description: This class manages stereo image capture, disparity and depth map calculation, as well as result processing and display.
- Attributes:

– cam capture: Instance of DualCameraCapture used for capturing images.

– baseline: Distance between the cameras (in meters).

– focal: Focal length of the camera.

– block size: Block size for stereo matching.

– P1: Weight for cost regularization.

– P2: Weight for cost regularization.

– min disp: Minimum disparity to consider.

– max disp: Maximum disparity to consider.

– uniqueRatio: Uniqueness ratio for stereo matching.

– speckleWindowSize: Window size for speckle filtering.

– speckleRange: Range of values for speckle filtering.

– disp12MaxDiff: Maximum difference between left and right disparities. – stop event: Event to stop processes.
– n: Counter for the number of saved images.
– images: Dictionary to store captured and rectified images.
– disparity: Calculated disparity map.
– disparity normalized: Normalized disparity map for display. – depth: Calculated depth map.
1.4.1 | Method | init
- Description: Initializes the parameters for stereo vision.
- Arguments:

– cam capture: DualCameraCapture - Instance of the class for capturing
| images.
– baseline: float - Distance between the cameras.
– focal: float - Focal length of the camera.
– block size: int - Block size for stereo matching. – P1: int - Weight for cost regularization.
– P2: int - Weight for cost regularization.
– min disp: int - Minimum disparity to consider.
– max disp: int - Maximum disparity to consider.
– uniqueRatio: int - Uniqueness ratio for stereo matching. – speckleWindowSize: int - Window size for speckle filtering.
– speckleRange: int - Range of values for speckle filtering.
– disp12MaxDiff: int - Maximum difference between left and right disparities.
- Returns: None.
- Usage example:

stereo_vision = StereoVision (
cam_capture = DualCameraCapture ( left_cam_id =0 , right_cam_id =1 , preview_size =(800 , 600) ) ,
baseline =0.06 ,
focal =1300 ,
block_size =15 ,
| P1 =150 , P2 =64 ,

min_disp = -16 ,
max_disp =128 ,
uniqueRatio =4 ,
speckleWindowSize =200 ,
speckleRange =4 ,
disp12MaxDiff =0

)

### 1.4.2 Method stereo taking

- Description: Captures and rectifies stereo images.
- Arguments: None.
- Returns: None.
- Usage example:

1 stereo_vision . stereo_taking ()

### 1.4.3 Method save images

- Description: Saves the images and the normalized disparity map.
- Arguments: None.
- Returns: None.
- Usage example:

1 stereo_vision . save_images ()

### 1.4.4 Method depth map calcul

- Description: Calculates the disparity map from the rectified images.
- Arguments: None.
- Returns: None.
- Usage example:

1 stereo_vision . depth_map_calcul ()

### 1.4.5 Method depth calcul

- Description: Calculates the depth for each pixel from the disparity map.
- Arguments: None.
- Returns: None.
- Usage example:

1 stereo_vision . depth_calcul ()

### 1.4.6 Method process stereo

- Description: Processes the depth map using DepthMapProcessor.
- Arguments: None.
- Returns: None.
- Usage example:

1 stereo_vision . process_stereo ()

### 1.4.7 Method capture and compute

- Description: Captures images, calculates the disparity map and depth, and then puts the results in a queue.
- Arguments:

– queue: Queue - Queue for passing results between processes.

- Returns: None.
- Usage example:
1 | queue = Queue ()
2 | stereo_vision . capture_and_compute ( queue )

### 1.4.8 Method depth map display

- Description: Displays the disparity map and depth from the results in the queue.
- Arguments:

– queue: Queue - Queue for obtaining calculated results.

- Returns: None.
- Usage example:
1 | queue = Queue ()
2 | stereo_vision . depth_map_display ( queue )

### 1.4.9 Method process and display

- Description: Creates processes for capturing and computing images, as well as displaying the results.
- Arguments: None.
- Returns: None.
- Usage example:

1 stereo_vision . process_and_display ()

### 1.5 Class TofCamera

- Description: This class handles capturing images from a ToF camera, processing depth and amplitude data, and displaying the results.
- Attributes:

– cam: Instance of ArducamCamera for the ToF camera.

– max distance: Maximum measurable distance by the camera (in meters).

– frame: Current frame captured by the camera.

– amplitude buf: Buffer for amplitude data.

– depth buf: Buffer for depth data.

– depth normalized: Normalized depth map for display.

– result image: Resulting image after processing.

– n: Counter for saved image names.

1.5.1 | Method | init
- Description: Initializes the ToF camera with the maximum distance parameters.
- Arguments:

– max distance: float - Maximum measurable distance by the camera (in me-
| ters).
- Returns: None.
- Usage example:

1 tof_camera = TofCamera ( max_distance =4)

### 1.5.2 Method process frame

- Description: Processes the captured frame to produce a resulting image by com-bining depth and amplitude data.
- Arguments: None.
- Returns: np.ndarray - Resulting image after processing.
- Usage example:

1 result_image = tof_camera . process_frame ()

### 1.5.3 Method capture image

- Description: Saves the resulting image under the name tof{n}.png.
- Arguments: None.
- Returns: None.
- Usage example:

1 tof_camera . capture_image ()

### 1.5.4 Method process tof

- Description: Processes the depth map using DepthMapProcessor to analyze and extract contours.
- Arguments: None.
- Returns: None.
- Usage example:

1 tof_camera . process_tof ()

### 1.5.5 Method continuous display

- Description: Captures and displays images continuously from the ToF camera, with options to save and process images.
- Arguments: None.
- Returns: None.
- Usage example:

1 tof_camera . continuous_display ()

### 1.5.6 Method cleanup

- Description: Stops and closes the camera, and destroys all OpenCV windows.
- Arguments: None.
- Returns: None.
- Usage example:

1 tof_camera . cleanup ()

### 1.5.7 Method get depth buf

- Description: Returns the current depth buffer.
- Arguments: None.
- Returns: np.ndarray - Depth buffer.
- Usage example:

1 depth_buf = tof_camera . get_depth_buf ()

### 1.5.8 Method get depth normalized

- Description: Returns the normalized depth map.
- Arguments: None.
- Returns: np.ndarray - Normalized depth map.
- Usage example:

1 depth_normalized = tof_camera . get_depth_normalized ()

### 1.6 Class DepthMapProcessor

- Description: This class handles processing of depth and disparity maps, including segmentation, calculating average amplitudes, and drawing contours.
- Attributes:

– depth map original: Original depth map.

– depth map normalized: Normalized disparity map.

– pixel min: Minimum number of non-zero pixels required to consider a segment (default 15000).

– min contour area: Minimum area for contours to be considered (default 10).

– thresholds: List of thresholds for disparity segmentation.

– kernel size: Kernel size for morphological operations (default 5).

– dilate iterations: Number of iterations for dilation (default 1).

– erode iterations: Number of iterations for erosion (default 2).

– segmented image: Segmented image after applying thresholds.

– contours: List of found contours.

– mean amplitudes: Dictionary of average amplitudes for each contour.

1.6.1 | Method | init
- Description: Initializes the DepthMapProcessor class with the provided parameters.
- Arguments:

– depth map: np.ndarray - Original depth map.

– disparity: np.ndarray - Normalized disparity map.

– pixel min: int - Minimum number of non-zero pixels required to consider a segment (default 15000).

– min contour area: int - Minimum area for contours to be considered (default 10).

– thresholds: list - List of thresholds for disparity segmentation.

– kernel size: int - Kernel size for morphological operations (default 5).

– dilate iterations: int - Number of iterations for dilation (default 1).

– erode iterations: int - Number of iterations for erosion (default 2).

- Returns: None.
- Usage example:
1 | depth_map = np . zeros ((480 , 640) ) | # Example depth map
2 | disparity = np . zeros ((480 , 640) ) | # Example disparity map
3 | processor = DepthMapProcessor ( depth_map , disparity )

### 1.6.2 Method apply morphological operations

- Description: Applies morphological operations (dilation and erosion) to the specified image.
- Arguments:

– image: np.ndarray - Image to process.

- Returns: np.ndarray - Image after applying morphological operations.
- Usage example:

1 processed_image = processor . apply_morphological_operations ( image )

### 1.6.3 Method calculate mean amplitude

- Description: Calculates the average amplitude for each specified contour.
- Arguments:

– contours: list - List of contours found in the image.

- Returns: dict - Dictionary of average amplitudes for each contour.
- Usage example:

1 mean_amplitudes = processor . calculate_mean_amplitude ( contours )

### 1.6.4 Method find and draw contours

- Description: Finds and draws contours in the processed image.
- Arguments:

– processed image: np.ndarray - Image after morphological operations.

- Returns: np.ndarray - Image with drawn contours.
- Usage example:

1 image_with_contours = processor . find_and_draw_contours ( processed_image )

### 1.6.5 Method process contour

- Description: Processes contours by applying morphological operations, finding and drawing contours, and calculating average amplitudes for the found contours.
- Arguments: None.
- Returns: None.
- Usage example:

1 processor . process_contour ()

### 1.6.6 Method process disparity image

- Description: Processes the disparity image by segmenting it according to the defined thresholds, and then applying contour processing on each segment.
- Arguments: None.
- Returns: None.
- Usage example:

1 processor . process_disparity_image ()

### 1.7 Utility Functions

### 1.7.1 Function calculate histogram

- Description: Calculates the histogram of pixel values in the image.
- Arguments:

– image: np.ndarray - Image to analyze.

- Returns: np.ndarray - Histogram of pixel values.
- Usage example:

1 hist = calculate_histogram ( image )

### 1.7.2 Function count non zero pixels from histogram

- Description: Counts the number of non-zero pixels from the pixel value histogram.
- Arguments:

– hist: np.ndarray - Histogram of pixel values.

- Returns: int - Total number of non-zero pixels.
- Usage example:

1 non_zero_count = count_non_zero_pixels_from_histogram ( hist )

### 1.7.3 Function plot histogram

- Description: Plots and displays the histogram of pixel values.
- Arguments:

– title: str - Title of the plot.

– hist: np.ndarray - Histogram of pixel values.

- Returns: None.
- Usage example:

1 plot_histogram (" Pixel Histogram ", hist )

## 2 Functions

### 2.1 Function folder create

- Description: Checks if a folder exists; if not, it creates one.
- Arguments:

– folder: str - Path of the folder to check/create.

- Returns: None.
- Usage example:

1 folder_create (’path /to/ folder ’)

### 2.2 Function file create

- Description: Creates a file of the specified type in a given folder (optional).
- Arguments:

– data: np.ndarray, list, or other - Data to save in the file.
– file name: str - Name of the file to create (without extension).

– file type: str - Type of file to create (’csv’, ’image’, ’npy’, etc.).

– folder name: str (optional) - Folder in which to create the file.

- Returns: None.
- Usage example:
1 | file_create ( data , ’ example_image ’, ’png ’, ’path /to/ folder ’)
2 | file_create ( data , ’ example_array ’, ’npy ’)
3 | file_create ( data , [[ ’header1 ’, ’header2 ’] , [1 , 2]] , ’csv ’, ’path /to
| / folder ’)

### 2.3 Function show image

- Description: Displays an image with a specified colormap.
- Arguments:

– title: str - Title of the display window.

– image: np.ndarray - Image to display.
– cmap: str (optional) - OpenCV colormap to apply (’gray’, ’jet’, ’rainbow’, etc.).
- Returns: None.
- Usage example:

1 show_image (’Displayed Image ’, image , ’jet ’)

### 2.3.1 List of Colormaps

- Available Colormaps:

– autumn

– bone

– jet

– winter

– rainbow

– ocean

– summer

– spring

– cool

– hsv

– pink

– hot

– parula

– magma

– inferno

– plasma

– viridis

– cividis

– twilight

– twilight shifted

– turbo

– deepgreen

## 3 Camera and Process Management

### 3.1 Function calibrate cameras

- Description: Calibrates the cameras by taking pictures of a checkerboard and using a calibration process.
- Arguments:

– cam capture: Instance of DualCameraCapture for capturing images.

- Returns: None.
- Usage example:

1 calibrate_cameras ( cam_capture )

### 3.2 Function run tof camera

- Description: Function to run the ToF camera continuously and update a queue with depth data.
- Arguments:

– camera queue: Queue to store camera data.

- Returns: None.
- Usage example:

1 run_tof_camera ( camera_queue )

### 3.3 Function run stereo vision

- Description: Function to run stereo vision and return the disparity and depth results.
- Arguments: None.
- Returns: Tuple containing normalized disparity and depth.
- Usage example:

1 disparity_normalized , depth = run_stereo_vision ()

### 3.4 Function terminate processes

- Description: Terminates the given processes.
- Arguments:

– processes: List of processes to terminate.

- Returns: None.
- Usage example:

1 terminate_processes ( processes )

### 3.5 Function kill zombie processes

- Description: Terminates the zombie processes detected on the system.
- Arguments: None.
- Returns: None.
- Usage example:

1 kill_zombie_processes ()

### 3.6 Function clean temp dirs

- Description: Cleans the specified temporary directories.
- Arguments:

– directories: List of directories to clean.

- Returns: None.
- Usage example:

clean_temp_dirs ([ ’/tmp ’, ’/var/tmp ’])

### 3.7 Function cleanup

- Description: Performs system cleanup and frees memory.
- Arguments: None.
- Returns: None.
- Usage example:

cleanup ()

## 4 Main Script Execution

if __name__ == " __main__ ":
cleanup ()
folder_create (’data ’)
folder_create (’image ’)
folder_create (’corner ’)

calib_choice = input ("Do you want to calibrate the cameras (y/n)? ") . strip () . lower ()

if calib_choice == "y":
cam_capture = DualCameraCapture ( left_cam_id =2 , right_cam_id =1 , preview_size =(840 , 820) )
calibrate_cameras ( cam_capture )
elif calib_choice == "n":
print (" Cameras will not be calibrated .")
else :
print (" Invalid choice . Please enter ’y’ or ’n ’.") exit (1)

# Initialize queues for inter - process communication camera_queue = multiprocessing . Queue ()

# Create processes

tof_process = multiprocessing . Process ( target = run_tof_camera , args =( camera_queue ,) )

23 | stereo_process = multiprocessing . Process ( target = run_stereo_vision )

24
25 | # Start processes
26 | tof_process . start ()
27 | stereo_process . start ()

28
29 | processes = [ tof_process , stereo_process ]

30
31 | # Wait for processes to finish
32 | try :
33 | # Keep processes alive
34 | while True :
35 | sleep (1)
36 | except KeyboardInterrupt :
37 | print (" Interruption detected . Stopping processes ...")
38 | finally :
39 | # Stop processes
40 | terminate_processes ( processes )
41 | print ("All processes have been stopped .")
42 | cleanup ()
43 | sys . exit (0)

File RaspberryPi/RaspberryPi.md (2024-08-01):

# Raspberry Pi - Installation Guide

This guide provides instructions for installing various programming software on your Raspberry Pi.

## Prerequisites

Before starting, make sure you have access to a functional Raspberry Pi and are connected to the Internet.

## Software Installation

### 1. Python

Python is a popular and widely used programming language. On Raspberry Pi, Python is generally pre-installed. You can check the Python version with the following command in the terminal:

```bash
python --version
```

If Python is not installed, you can install it by running the following commands:

```bash
sudo apt update
sudo apt install python3
```

### 2. Visual Studio Code (VS Code)
Visual Studio Code is a very popular open-source code editor developed by Microsoft. It offers extensive support for many programming languages.

To install Visual Studio Code on your Raspberry Pi, follow these steps:

```bash
sudo apt update
sudo apt install code
```

After installation, you can launch VS Code from the menu or using the `code` command in the terminal.

### 3. Thonny
Thonny is a user-friendly integrated development environment (IDE) for Python that is especially suitable for beginners. To install it, follow the provided steps.

```bash
sudo apt update
sudo apt install thonny
```
After installation, you can launch Thonny from the menu or using the terminal command.

## Installation des librairies

To install libraries, first open a terminal. The sections below show how to install various libraries.

But first, you can check which libraries are already installed. To do this, enter the relevant command.

```bash
sudo apt install python-
```

To verify the installation of a library, you can use the command provided, replacing `<library_name>` with the name of the library.
```bash
pip show <librarie_name>
```

### numpy

```bash
sudo apt install python-numpy
```

### matplotlib
```bash
sudo apt install python-matplotlib
```

### picamera2

If you need to update Picamera2, you can do so by performing a full system update or by specifically installing it via the terminal. 

```bash
sudo apt update
sudo apt install -y python3-picamera2
```

This ensures that Picamera2 is updated to the latest version available in the repositories.

If you are using the full version of Raspberry Pi OS and need the GUI dependencies for Picamera2, you can install them with the provided command. 
```bash
sudo apt install -y python3-pyqt5 python3-opengl
```
This installs PyQt5 and the necessary OpenGL dependencies for Picamera2's graphical features.

If you are using Raspberry Pi OS Lite and want to use GUI features with Picamera2, you will need to install PyQt5 and OpenGL separately.

```bash
sudo apt install -y python3-pyqt5 python3-opengl
```

If you want to install Picamera2 without the additional GUI dependencies, use the provided command.

```bash
sudo apt install -y python3-picamera2 --no-install-recommends
```

### openCV

```bash
sudo apt-get install python3-opencv
```

### ArduArducamDepthCamera
To install this library, visit the ToF.md page.

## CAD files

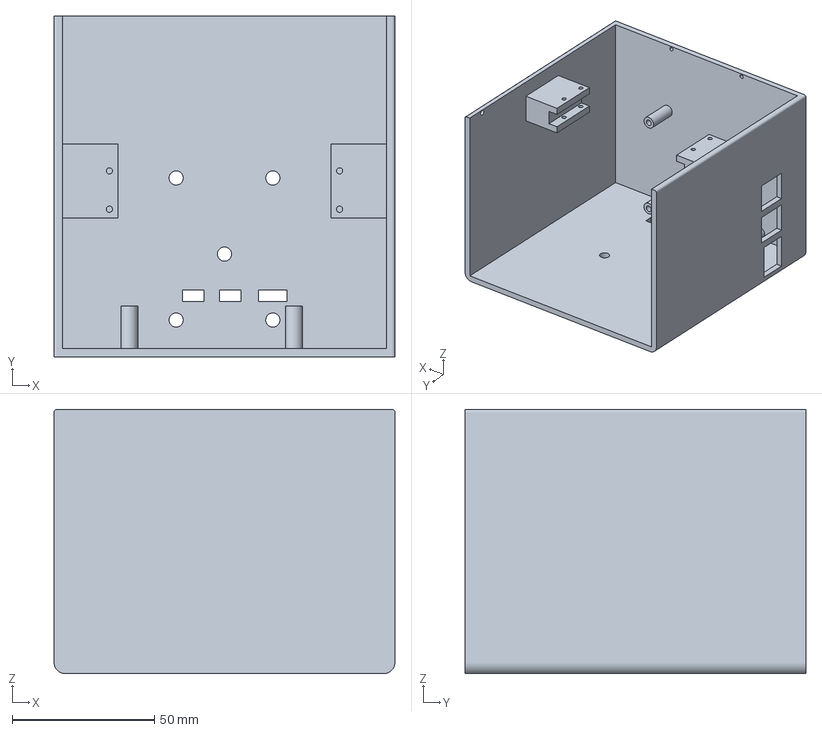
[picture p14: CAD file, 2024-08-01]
support/depth_camera_support_box.3MF
120.0 x 120.0 x 93.0 mm

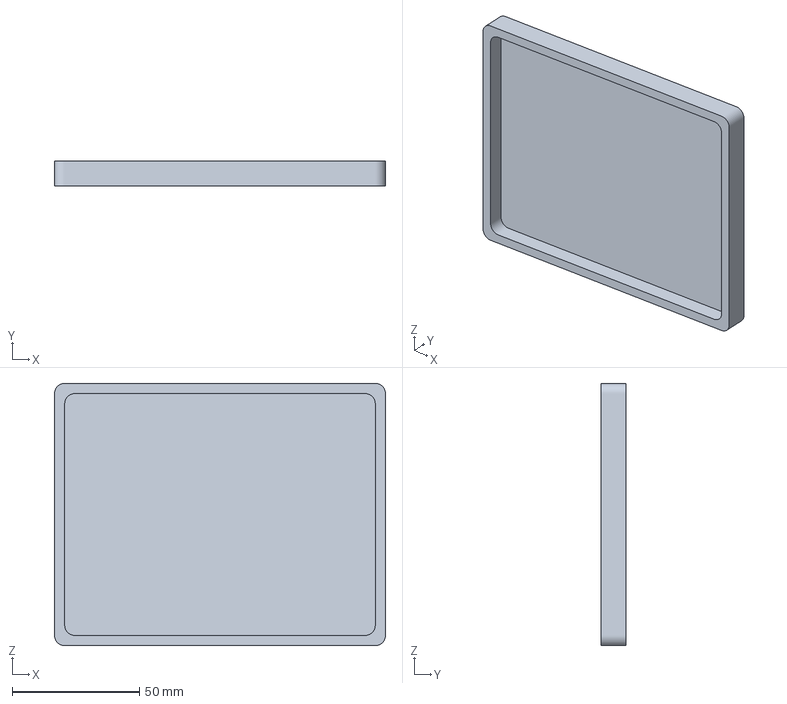
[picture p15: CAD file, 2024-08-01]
support/depth_camera_support_top.3MF
130.0 x 10.0 x 103.0 mm

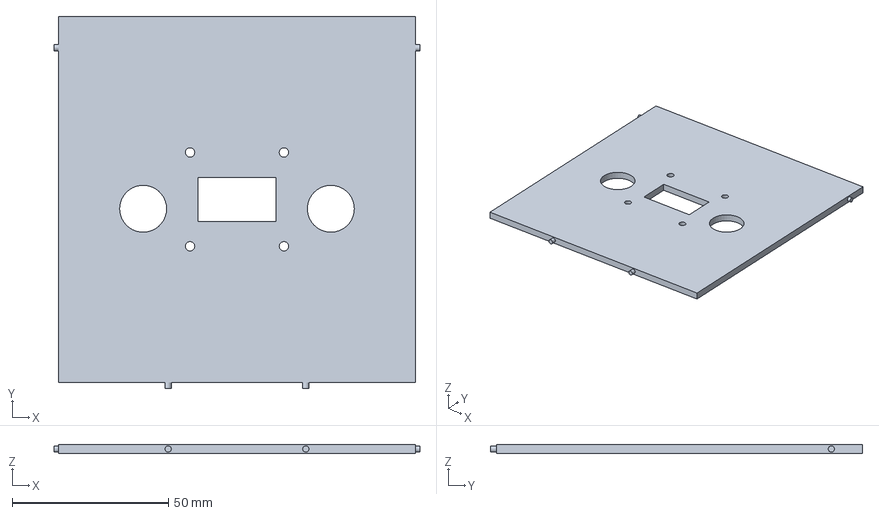
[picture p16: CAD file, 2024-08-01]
support/depth_camera_support_face.3MF
117.0 x 119.0 x 3.00 mm

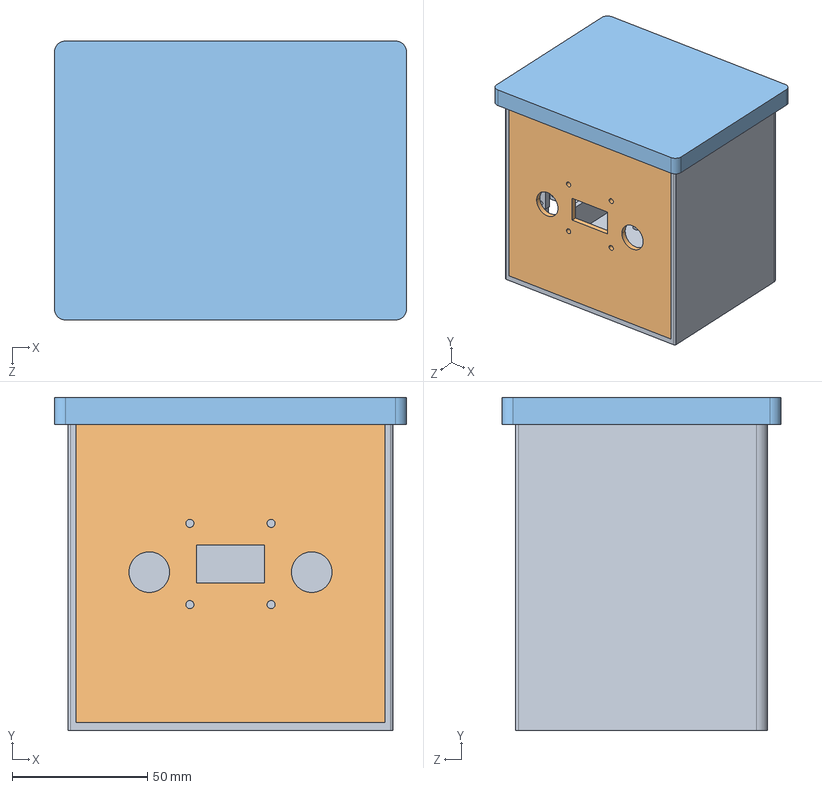
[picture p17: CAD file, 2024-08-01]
support/depth_camera_support.STEP
130.0 x 123.0 x 103.0 mm
Boite_raspberry
Face avant
couvercle_boite

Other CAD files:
support/depth_camera_support.3MF

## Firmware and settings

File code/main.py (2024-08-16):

import multiprocessing
from time import sleep
import cv2
import psutil
import sys
import os
import shutil
import signal

from tof_sensor import TofCamera
from stereo_vision import StereoVision, DualCameraCapture
from calibration_camera import Calibrator
from exception import folder_create


def calibrate_cameras(cam_capture):
    print("Starting camera calibration...")

    # Calibration parameters
    img_width = 840
    img_height = 820
    image_size = (img_width, img_height)

    # Capture the necessary photos for calibration
    nbr_photos = int(input("Enter the number of images to capture for calibration: "))
    rows = int(input("Enter the number of rows on the checkerboard: "))
    columns = int(input("Enter the number of columns on the checkerboard: "))
    square_size = 2.4  # Checkerboard square size

    cam_capture.capture_images(nbr_photos=nbr_photos, image_folder="image")

    calibrator = Calibrator(rows, columns, square_size, image_size)
    calibration = calibrator.calibration_process(nbr_photos, 'image')

    # Save calibration data
    calibration.save('data')

    print("Calibration completed.")


def run_tof_camera(camera_queue):
    tof_camera = TofCamera(max_distance=4)
    tof_camera.continuous_display()
    while True:
        depth_buf = tof_camera.get_depth_buf()
        depth_normalized = tof_camera.get_depth_normalized()
        if depth_buf is not None and depth_normalized is not None:
            camera_queue.put((depth_buf, depth_normalized))
        sleep(1)


def run_stereo_vision():
    img_width = 840
    img_height = 820
    image_size = (img_width, img_height)
    cam_capture = DualCameraCapture(left_cam_id=2, right_cam_id=1, preview_size=image_size)
    stereo_vision = StereoVision(cam_capture)
    stereo_vision.process_and_display()

    disparity_normalized = stereo_vision.disparity_normalized
    depth = stereo_vision.depth
    return disparity_normalized, depth


def terminate_processes(processes):
    """Terminates the given processes."""
    for proc in processes:
        if proc.is_alive():
            proc.terminate()
            proc.join()


def kill_zombie_processes():
    """Kills zombie processes."""
    for proc in psutil.process_iter(['pid', 'status']):
        try:
            if proc.info['status'] == psutil.STATUS_ZOMBIE:
                print(f"Zombie process detected: PID {proc.info['pid']}")
                os.kill(proc.info['pid'], signal.SIGKILL)
                print(f"Zombie process {proc.info['pid']} killed.")
        except (psutil.NoSuchProcess, psutil.AccessDenied) as e:
            print(f"Error handling process {proc.info['pid']}: {e}")


def clean_temp_dirs(directories):
    """Cleans the specified temporary directories."""
    for directory in directories:
        try:
            for filename in os.listdir(directory):
                file_path = os.path.join(directory, filename)
                try:
                    if os.path.isfile(file_path) or os.path.islink(file_path):
                        os.unlink(file_path)
                    elif os.path.isdir(file_path):
                        shutil.rmtree(file_path)
                except Exception as e:
                    print(f"Error cleaning {file_path}: {e}")
        except Exception as e:
            print(f"Error cleaning {directory}: {e}")


def cleanup():
    """Performs cleanup operations."""
    kill_zombie_processes()
    clean_temp_dirs(['/tmp', '/var/tmp'])
    print("Memory freed.")
    print("System cleanup completed.")


if __name__ == "__main__":
    folder_create('data')
    folder_create('image')
    folder_create('corner')

    calib_choice = input("Do you want to calibrate the cameras (y/n)? ").strip().lower()

    if calib_choice == "y":
        cam_capture = DualCameraCapture(left_cam_id=2, right_cam_id=1, preview_size=(840, 820))
        calibrate_cameras(cam_capture)
    elif calib_choice == "n":
        print("Cameras will not be calibrated.")
    else:
        print("Invalid choice. Please enter 'y' or 'n'.")
        exit(1)

    # Initialize queues for inter-process communication
    camera_queue = multiprocessing.Queue()

    # Create processes
    tof_process = multiprocessing.Process(target=run_tof_camera, args=(camera_queue,))
    stereo_process = multiprocessing.Process(target=run_stereo_vision)

    # Start processes
    tof_process.start()
    stereo_process.start()

    processes = [tof_process, stereo_process]

    # Wait for processes to finish
    try:
        # Keep processes alive
        while True:
            sleep(1)
    except KeyboardInterrupt:
        print("Interrupt detected. Stopping processes...")
    finally:
        # Stop processes
        terminate_processes(processes)
        print("All processes have been stopped.")
        cleanup()
        sys.exit(0)

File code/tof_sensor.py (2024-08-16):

import sys  # Import for exception handling and system operations
import cv2  # Import OpenCV for image processing
import numpy as np  # Import NumPy for mathematical operations
import ArducamDepthCamera as ac  # Import library for the Arducam ToF camera
from depth_traitement import DepthMapProcessor  # Import class for depth map processing


class TofCamera:
    def __init__(self, max_distance=4):
        """
        Initialize the ToF camera with maximum distance parameters.

        :param max_distance: Maximum measurable distance by the camera in meters
        """
        self.cam = ac.ArducamCamera()  # Create an instance of the Arducam camera
        self.max_distance = max_distance  # Maximum distance to normalize the depth
        self.frame = None  # Current frame captured by the camera
        self.amplitude_buf = None  # Buffer for amplitude data
        self.depth_buf = None  # Buffer for depth data
        self.depth_normalized = None  # Normalized depth map for display
        self.result_image = None  # Resulting image after processing
        self.n = 0  # Counter for saved image names

    # Have to be implemented
    def water_equation(self):
        self.depth_water = self.depth_buf * 0.75  # distance = d_air * (c_water/c_air)

    def process_frame(self) -> np.ndarray:
        """
        Process the captured frame to produce a resulting image by combining depth and amplitude data.

        :return: Resulting image after processing
        """
        if self.depth_buf is None or self.amplitude_buf is None:
            raise ValueError("Depth buffer and amplitude buffer must not be None.")

        # Convert NaN values to zero for the depth buffer
        self.depth_buf = np.nan_to_num(self.depth_buf)
        # Threshold amplitude data
        self.amplitude_buf = np.where(self.amplitude_buf <= 7, 0, 255)

        # Normalize depth data
        normalized_depth = (1 - (self.depth_buf / self.max_distance)) * 255
        normalized_depth = np.clip(normalized_depth, 0, 255).astype(np.uint8)
        self.depth_normalized = normalized_depth
        # Combine normalized depth and amplitude data
        result_frame = normalized_depth & self.amplitude_buf.astype(np.uint8)
        return result_frame

    def capture_image(self):
        """
        Save the resulting image as tof{n}.png.
        """
        if self.result_image is not None:
            cv2.imwrite(f"tof{self.n}.png", self.result_image)
            print(f"Image saved as tof{self.n}.png")
            self.n += 1
        else:
            print("No image to save")

    def process_tof(self):
        """
        Process the depth map using DepthMapProcessor to analyze and extract contours.
        """
        # Replace for a under water usage
        processor = DepthMapProcessor(
                depth_map=self.depth_buf, # self.depth_water
                disparity=self.depth_normalized,
                pixel_min=18000,
                min_contour_area=20,
                thresholds=[50, 100, 200, 255],
                kernel_size=5,
                dilate_iterations=1,
                erode_iterations=3
            )
        processor.process_disparity_image()

    def apply_median_filter(self, image: np.ndarray, ksize: int = 5) -> np.ndarray:
        """ Apply a median filter at the image
        :param image : input image
        :param ksize : Kernel size of the median filter
        :return: Filtered image
        """
        return cv2.medianBlur(image, ksize)

    def continuous_display(self):
        """
        Continuously capture and display images from the ToF camera, with options to save and process images.
        """
        # Open the connection to the ToF camera and start the depth data stream
        if self.cam.open(ac.TOFConnect.CSI, 0) != 0 or self.cam.start(ac.TOFOutput.DEPTH) != 0:
            print("Failed to initialize or start the camera")
            sys.exit(1)

        # Set the maximum distance of the camera
        self.cam.setControl(ac.TOFControl.RANG, self.max_distance)

        try:
            while True:
                # Capture a frame from the camera
                self.frame = self.cam.requestFrame(200)
                if self.frame is not None:
                    # Get depth and amplitude data
                    self.depth_buf = self.frame.getDepthData()
                    self.amplitude_buf = self.frame.getAmplitudeData()
                    self.cam.releaseFrame(self.frame)  # Release the frame after processing

                    # Normalize and process amplitude data
                    self.amplitude_buf = np.clip(self.amplitude_buf * (255 / 1024), 0, 255)

                    # Process the frame to get the resulting image
                    self.result_image = self.process_frame()
                    # Use for water application
                    # self.water_equation()

                    #Apply a median filter
                    self.result_image = self.apply_median_filter(self.result_image)

                    # Apply a color map for better display
                    self.result_image = cv2.applyColorMap(self.result_image, cv2.COLORMAP_JET)

                    # Display the resulting image
                    cv2.imshow("ToF Camera", self.result_image)

                    # Handle keyboard input
                    key = cv2.waitKey(1) & 0xFF
                    if key == ord('q'):  # Quit if 'q' key is pressed
                        break
                    elif key == ord('s'):  # Save the image if 's' key is pressed
                        self.capture_image()
                    elif key == ord('t'):  # Process depth data if 't' key is pressed
                        self.process_tof()
                else:
                    print("Failed to capture frame")

        except KeyboardInterrupt:
            pass
        finally:
            self.cleanup()  # Clean up resources at the end of execution

    def cleanup(self):
        """
        Stop and close the camera, and destroy all OpenCV windows.
        """
        self.cam.stop()
        self.cam.close()
        cv2.destroyAllWindows()

    def get_depth_buf(self):
        """
        Return the current depth buffer.

        :return: Depth buffer
        """
        return self.depth_buf

    def get_depth_normalized(self):
        """
        Return the normalized depth map.

        :return: Normalized depth map
        """
        return self.depth_normalized

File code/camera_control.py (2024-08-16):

import time
from picamera2 import Picamera2, Preview
import os
import cv2  # OpenCV for displaying images

# Import the show_image function
from exception import show_image


class DualCameraCapture:
    def __init__(self, left_cam_id=0, right_cam_id=1, preview_size=(840, 820),
                 preview_type=Preview.QTGL, capture_delay=0, interval=5):
        """
        Initializes the DualCameraCapture class with camera parameters.

        :param left_cam_id: ID of the left camera (default 0)
        :param right_cam_id: ID of the right camera (default 1)
        :param preview_size: Size of the preview (default (840, 820))
        :param preview_type: Type of preview (default Preview.QTGL)
        :param capture_delay: Delay before capturing the image (default 0)
        :param interval: Interval between image captures (default 5)
        """
        self.left_cam_id = left_cam_id
        self.right_cam_id = right_cam_id
        self.preview_size = preview_size
        self.preview_type = preview_type
        self.capture_delay = capture_delay
        self.interval = interval

    def capture_and_save_image(self, picam_id, filename):
        """
        Captures and saves an image from the specified camera.

        :param picam_id: ID of the camera to use
        :param filename: Name of the file to save the image
        """
        # Create an instance of Picamera2 with the specified ID
        picam = Picamera2(picam_id)
        # Create preview configuration with the specified size
        preview_config = picam.create_preview_configuration(main={"size": self.preview_size})
        picam.configure(preview_config)
        # Start the camera preview with the specified preview type
        picam.start_preview(self.preview_type)
        # Start capturing
        picam.start()
        # Delay to allow the camera to stabilize before capturing
        time.sleep(self.capture_delay)
        # Capture the image and save it to the specified file
        metadata = picam.capture_file(filename)
        print(f"Image captured {filename}: {metadata}")
        # Close the camera after capturing
        picam.close()

    def display_images(self, left_filename, right_filename):
        """
        Displays the captured images from the specified files.

        :param left_filename: Name of the left image file
        :param right_filename: Name of the right image file
        """
        # Read the images from the specified files
        left_image = cv2.imread(left_filename)
        right_image = cv2.imread(right_filename)

        # Display the images using the imported show_image function
        show_image("Left Image", left_image, cmap='gray')
        show_image("Right Image", right_image, cmap='gray')

    def validate_images(self):
        """
        Validates if the captured images are acceptable.

        :return: True if the images are acceptable, otherwise False
        """
        while True:
            # Ask the user to validate the images
            user_input = input("Are the images acceptable? (y/n): ").strip().lower()
            if user_input in ["y", "n"]:
                # Return True if the user accepts the images, otherwise False
                return user_input == "y"
            print("Invalid input. Please enter 'y' or 'n'.")

    def capture_images(self, nbr_photos, image_folder):
        """
        Captures a specified number of pairs of images and saves them to the specified folder.

        :param nbr_photos: Number of pairs of images to capture
        :param image_folder: Folder to save the images
        """
        photo_counter = 0
        while photo_counter < nbr_photos:
            # Wait before capturing the next pair of images
            time.sleep(self.interval)
            # Define filenames for left and right images
            left_filename = os.path.join(image_folder, f'left_{str(photo_counter + 1).zfill(2)}.png')
            right_filename = os.path.join(image_folder, f'right_{str(photo_counter + 1).zfill(2)}.png')

            # Capture and save images for the left and right cameras
            self.capture_and_save_image(self.left_cam_id, left_filename)
            self.capture_and_save_image(self.right_cam_id, right_filename)

            # Display the captured images for validation
            self.display_images(left_filename, right_filename)

            # Validate the images with the user
            if self.validate_images():
                photo_counter += 1
                print(f'Captured pair No {photo_counter}')
            else:
                print("Retrying images...")
